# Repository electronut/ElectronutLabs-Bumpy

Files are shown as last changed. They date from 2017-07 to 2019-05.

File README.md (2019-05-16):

> **Note**: This repository has been moved to our GitLab page on May 2019, and will not receive any updates or be monitored. Please follow this link to go to the new repository: https://gitlab.com/electronutlabs-public/ElectronutLabs-Bumpy

## What is Bumpy?

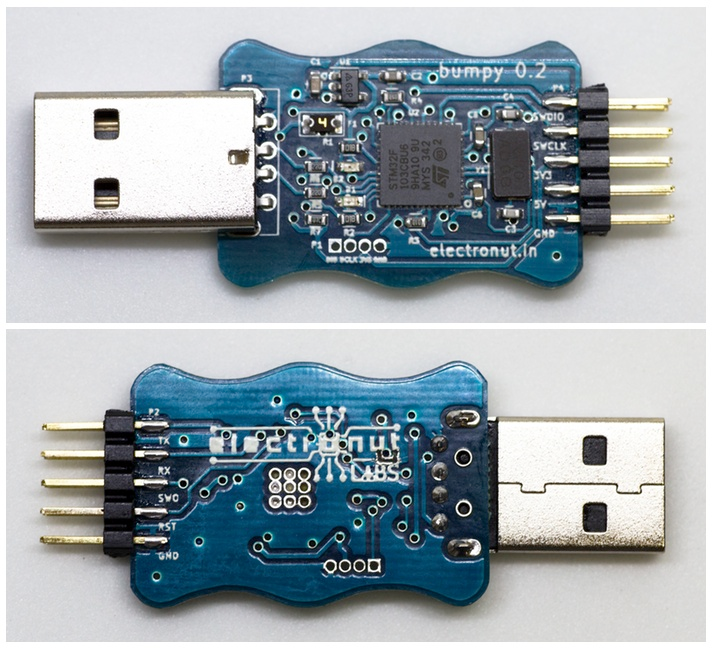
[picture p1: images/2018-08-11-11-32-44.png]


**Bumpy** is an inexpensive Open Source **blackmagic probe** compatible SWD debugger designed to
be used with ARM GDB. It supports [many platforms][3], but was primarily designed
for use with our Nordic Semiconductor nRF BLE boards.

When we built our [Bluey][1] nRF52 BLE dev board, we were looking for an inexpensive
option for our users to upload code to bluey and debug it using ARM GDB. We then came
across the [blackmagic probe][2] (BMP) project - an Open Source debugging tool for
embedded microprocessors. It greatly simplifies the debugging and code
uploading process using just ARM GDB - no need to run a GDB server or use an
additional complex tool like **openocd**. Although the BMP hardware is excellent,
it's bit beyond the budget of our target audience as an add-on programmer.
So we decided to make use of their liberal open source license and build something
that fits our budget, albeit with less capabilities.

**Bumpy** takes advantage of the **ST-Link** support of the BMP, and its design
is based on both BMP and Chinese **St-Link V2** clones available for cheap in the market.

Schematic : [download](schematic.pdf)

## Plugging in Bumpy

When you plug in Bumpy, you'll see two ports - one for blackmagic probe functionality
and the other for a UART you can use for printing debug messages without plugging
in a separate USB to serial adapter.

This is how it looks on *OS X*. (Linux should be similar.):

```
$ ls /dev/tty.usb**
/dev/tty.usbmodemD5C57BD1	/dev/tty.usbmodemD5C57BD3
```

This is how it looks on the Windows Device Manager:

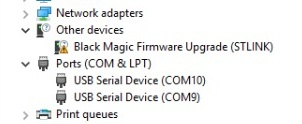
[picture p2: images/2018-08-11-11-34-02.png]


## Bumpy Firmware

Bumpy already comes with the blackmagic probe firmware. In case you need to build it, here's what you do:

### Building firmware

These instructions are for linux. First, clone bumpy firmware `git clone git@github.com:electronut/blackmagic.git -b bumpy`. Then `cd blackmagic` and run:

    make PROBE_HOST=bumpy

The directory `src` will contain the binaries.

To upload a specific version of firmware:
	
	dfu-util -s 0x08002000:leave:force -D blackmagic.bin

### Releases

We recommend using version v1.3 firmware, it has support for Nrf52840 and newer chip IDs for Nrf52832 etc., but automatic reset upon disconnect from GDB doesn't work in this one (though you can do `run` inside GDB to run the code). V1.2 is here for archival reasons.

#### Version 1.3

Download [link](https://github.com/electronut/ElectronutLabs-Bumpy/releases/download/v1.3/blackmagic.bin)

#### Version 1.2

Download [link](https://github.com/electronut/ElectronutLabs-Bumpy/releases/download/v1.2/blackmagic.bin)

#### Version 1.1

Download [link](https://github.com/electronut/ElectronutLabs-Bumpy/releases/download/v1.1/bumpy-rev1.1.bin)

## Updating Bumpy Firmware

The latest binaries are included in the [firmware](firmware) directory of this repository. You can download it directly from [here](https://github.com/electronut/ElectronutLabs-Bumpy/releases/download/v1.1/bumpy-rev1.1.bin).

In order to update the blackmagic probe firmware on Bumpy, you need to have [dfu-util](http://dfu-util.sourceforge.net/) installed in your system.

### Windows

* Download and extract the contents of **dfu-util-0.9-win64.zip** file.

* Add the location of **dfu-util.exe** executable, available in the extracted folder from above, to your
path variables.

* Ensure that dfu-util is part of your PATH variables by simply running a command prompt and typing **dfu-util**.

* Plug-in Bumpy. Wait until the onboard red LED turns on.

* In Windows, you need WinUSB or libusb drivers for dfu-util to work. These drivers can be installed using [Zadig](http://zadig.akeo.ie/).

* Run: **Zadig**.

* Select: **Black Magic Firmware Upgrade (STLINK) (Interface 4)** from the drop down menu.

* If no device is available for selection, go to: Options > List All Devices.

* Select **WinUSB** driver and click on **Install**.

* The above steps have enabled firmware update functionality over USB.

* Now, check that you are in the same directory as the **bumpy-rev1.1.bin**

* Run: `dfu-util -d 1d50:6018,:6017 -s 0x08002000:leave -D bumpy-rev1.1.bin`.

* Wait for firmware to load. The expected output is shown below:

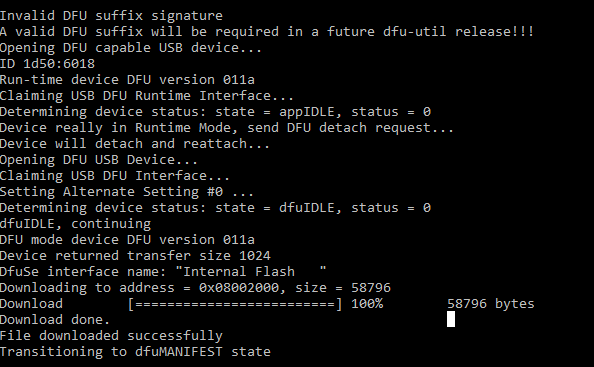
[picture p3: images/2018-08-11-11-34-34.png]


* Remove Bumpy and plugin again, to reset the chip.

The firmware has been updated successfully.

### Linux

Most Linux installations have packages for dfu-util, by default. Following are the install commands for some of these popular distributions.

**Ubuntu** & **Debian** 

`sudo apt-get install dfu-util`

**Fedora**

`sudo yum install dfu-util`

**Arch**

`sudo pacman -Sy dfu-util`

Once the installation is successful, simply plugin Bumpy and issue following command to update the firmware.

`sudo dfu-util -d 1d50:6018,:6017 -s 0x08002000:leave -D bumpy-rev1.1.bin`

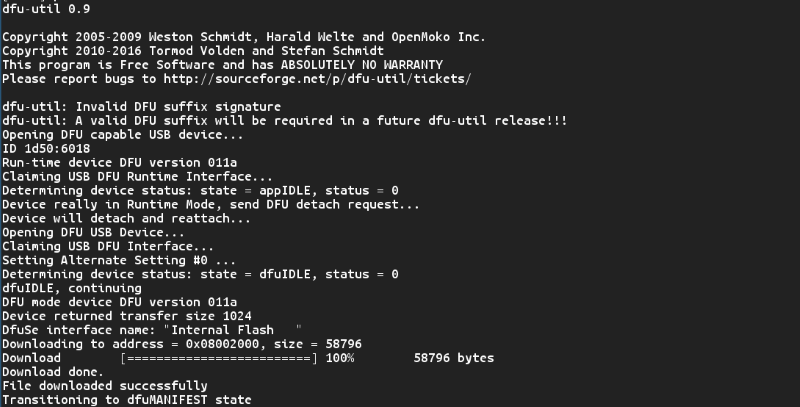
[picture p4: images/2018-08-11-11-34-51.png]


## Using Bumpy

Here are a few example of using Bumpy.

Jump To:

- [Using Bumpy with Bluey (Nordic nRF52832)](#bluey)
- [Using Bumpy with an STM32F100RB](#stm32f100)

<hr />

##  Using Bumpy with Bluey (Nordic nRF52832)

Here, we assume that you have files *blinky.hex* and *blinky.out* in the working
directory where you start GDB. (You can generate these files yourself using the
  *peripheral/blinky/pca10040/blank* example in the Nordic SDK.)

Connect the debugger to bluey as follows:

| Bumpy | bluey |
|---|---|
| 3.3 | VDD|
| GND | GND|
| SWCLK | SWCLK|
| SWDIO | SWDIO|

Here's what the hookup looks like:

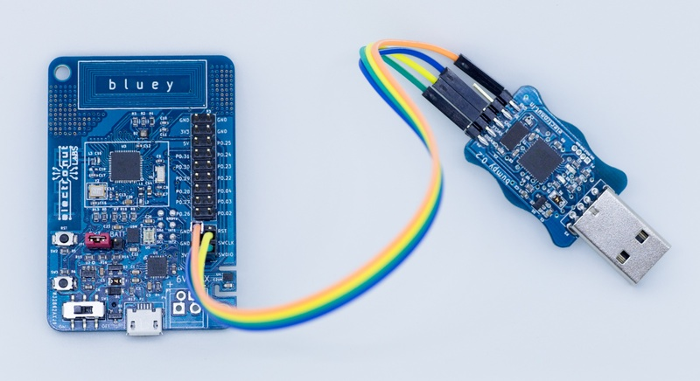
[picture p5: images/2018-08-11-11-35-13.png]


Now, open a command shell and run **arm-none-eabi-gdb**:

```
C:\Users\mahesh>arm-none-eabi-gdb
GNU gdb (GNU Tools for ARM Embedded Processors 6-2017-q1-update) 7.12.1.20170215-git
Copyright (C) 2017 Free Software Foundation, Inc.
License GPLv3+: GNU GPL version 3 or later <http://gnu.org/licenses/gpl.html>
This is free software: you are free to change and redistribute it.
There is NO WARRANTY, to the extent permitted by law.  Type "show copying"
and "show warranty" for details.
This GDB was configured as "--host=i686-w64-mingw32 --target=arm-none-eabi".
Type "show configuration" for configuration details.
For bug reporting instructions, please see:
<http://www.gnu.org/software/gdb/bugs/>.
Find the GDB manual and other documentation resources online at:
<http://www.gnu.org/software/gdb/documentation/>.
For help, type "help".
Type "apropos word" to search for commands related to "word".
(gdb)
```

Now you need to connect to the target. The Black Magic Probe hardware will
create two COM ports, and you need to connect to the first one for debugging.
(You can see the ports in the *Device Manager*.)

```
(gdb) target extended-remote COM5
Remote debugging using COM5
```

**Note**

On Windows, for ports >= `COM10`, add the prefix `\\.\`.

For example:

```
(gdb) target extended-remote COM3
(gdb) target extended-remote \\.\COM10
```

Now, we scan for targets. We're using SWD here.

```
(gdb) monitor swdp_scan
Target voltage: unknown
Available Targets:
No. Att Driver
 1      Nordic nRF52
```

You can see above that it found our nRF52 target - the chip in Bluey. Now
let's connect to it.

```
(gdb) attach 1
Attaching to Remote target
warning: No executable has been specified and target does not support
determining executable automatically.  Try using the "file" command.
0x0002099e in ?? ()
(gdb)
```

Now let's upload some code to the flash memory.

```
(gdb) file blinky.hex
Reading symbols from blinky.hex...(no debugging symbols found)...done.
```

Now let's run the program.

```
(gdb) run
Starting program: C:\mahesh\nRF5_SDK_12.2.0_f012efa\examples\peripheral\blinky\pca10040\blank\armgcc\_build\blinky.hex
```
At this point you'll be able to see the LED blinking on **bluey** in various colors.

Now we're ready to do some debugging. We'll use the *.out* file this time, since that has
the necessary code symbols required for debugging.

```
(gdb) file blinky.out
A program is being debugged already.
Are you sure you want to change the file? (y or n) y
Reading symbols from blinky.out...done.
(gdb) run
The program being debugged has been started already.
Start it from the beginning? (y or n) y
Starting program: C:\mahesh\nRF5_SDK_12.2.0_f012efa\examples\peripheral\blinky\pca10040\blank\armgcc\_build\blinky.out
```

Now press Ctrl-C.

```
Program received signal SIGINT, Interrupt.
0x00001990 in nrf_delay_us (number_of_us=500000) at ../../../../../../components/drivers_nrf/delay/nrf_delay.h:128
128     __ASM volatile (
(gdb) list
123     __STATIC_INLINE void nrf_delay_us(uint32_t number_of_us)
124     {
125         const uint32_t clock16MHz = CLOCK_FREQ_16MHz;
126         if (number_of_us)
127         {
128     __ASM volatile (
129     #if ( defined(__GNUC__) && (__CORTEX_M == (0x00U) ) )
130             ".syntax unified\n"
131     #endif
132     "1:\n"
(gdb)
```

As you can see, it's showing you the code being executed. Now let's put a breakpoint in
*main.c*:

```
(gdb) break main.c:43
Breakpoint 4 at 0x1a04: file ../../../main.c, line 43.
(gdb) run
The program being debugged has been started already.
Start it from the beginning? (y or n) y
Starting program: C:\mahesh\nRF5_SDK_12.2.0_f012efa\examples\peripheral\blinky\pca10040\blank\armgcc\_build\blinky.out

Breakpoint 4, main () at ../../../main.c:43
43                  nrf_delay_ms(500);
(gdb) list
38          while (true)
39          {
40              for (int i = 0; i < LEDS_NUMBER; i++)
41              {
42                  bsp_board_led_invert(i);
43                  nrf_delay_ms(500);
44              }
45          }
46      }
47
(gdb) p i
$2 = 0
(gdb) continue
Continuing.

Breakpoint 4, main () at ../../../main.c:43
43                  nrf_delay_ms(500);
(gdb) p i
$3 = 1
(gdb)
```

As you can see above, as we loop through, we can see *i* changing. Cool huh?

If you want to learn how to use GDB I highly recommend [Art of debugging][6] by
Norman Matloff and Peter Jay Salzman.

### Loading code with Softdevice

In the above example, we used the *blinky* code which did not have a Softdevice.
Since most of our use of this chip will use BLE and hence a Nordic Softdevice, let's
take the SDK example *ble_app_hrs* and see how to load it.

First, build *ble_app_hrs* to generate the program hex file. Then use the
Nordic *mergehex* tool to combine the softdevice and program as given below.
The softdevice cam be found in *components/softdevice* folder of the SDK.

```
c:\mahesh\tmp>mergehex -m s132_nrf52_3.0.0_softdevice.hex nrf52832_xxaa.hex -o out.hex
Parsing input hex files.
Merging files.
Storing merged file.

c:\mahesh\tmp>ls -l
total 467
-rw-r--r--    1 info     Administ   130859 May  8 08:33 nrf52832_xxaa.hex
-rw-r--r--    1 info     Administ   476926 May  8 08:35 out.hex
-rw-r--r--    1 info     Administ   346118 Jul 25  2016 s132_nrf52_3.0.0_softdevice.hex
```

Now load it using our Black Magic Probe clone as shown before.

```
(gdb) load out.hex
Loading section .sec1, size 0x964 lma 0x0
Loading section .sec2, size 0xf000 lma 0x1000
Loading section .sec3, size 0xe740 lma 0x10000
Loading section .sec4, size 0x1000 lma 0x1f000
Loading section .sec5, size 0xa5a4 lma 0x20000
Start address 0x0, load size 169544
Transfer rate: 17 KB/sec, 968 bytes/write.
(gdb) run
```

And now you'll see the HRS app running happily on **bluey**!

**Note**

`monitor erase_mass` can be used to erase the flash memory. It works for nRF52
but I am not sure if that's the case for all supported targets.

## Using the UART via USB on Bumpy

Bumpy supports UART, so you can use it for debugging your board without using up
another USB

Connect the debugger to bluey as follows:

| Bumpy | bluey |
|---|---|
| 3.3 | VDD|
| GND | GND|
| SWCLK | SWCLK|
| SWDIO | SWDIO|
| Rx | P0.TX|
| Tx | P0.RX|

*P0.TX* and *Po.RX* can be any pins - just configure them for UART in your program.

You UART setup should look something like this:

```C
static void uart_init(void)
{
    uint32_t                     err_code;
    const app_uart_comm_params_t comm_params =
    {
        RX_PIN_NUMBER, // use P0.RX
        TX_PIN_NUMBER, // use P0.TX
        RTS_PIN_NUMBER,
        CTS_PIN_NUMBER,
        APP_UART_FLOW_CONTROL_DISABLED,
        false,
        UART_BAUDRATE_BAUDRATE_Baud115200
    };

    APP_UART_FIFO_INIT( &comm_params,
                       UART_RX_BUF_SIZE,
                       UART_TX_BUF_SIZE,
                       uart_event_handle,
                       APP_IRQ_PRIORITY_LOWEST,
                       err_code);
    APP_ERROR_CHECK(err_code);

    // UART enabled
    uart_enabled = true;
}
```

##  Using Bumpy with an STM32F100RB

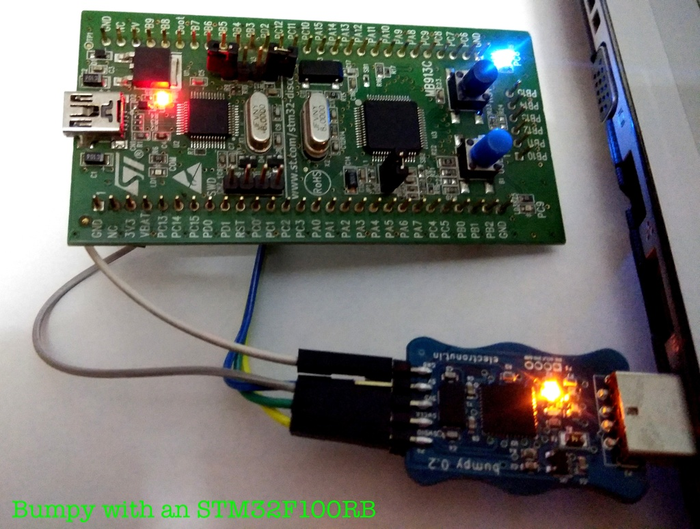
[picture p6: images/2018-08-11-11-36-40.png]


Click [here][8] to read about using Bumpy with an STM32F100RB chip. This examples compiles a minimal blink code for **STM32VLDiscovery** using **unicore-mx**.

## Using GDB in the Atom editor

[Atom][4] is gaining popularity an easy to use modern code editor. It has support for a
bewildering range of plugins, and so it has one for GDB as well - the [atom-gdb-debugger package][5].

Follow the instructions for installing the above plugin, and ensure that *arm-eabi-none-gdb* is in your PATH.

Search for "GDB Debugger" in the Atom help menu, and you'll find what you need.

The plugin is quite bare-bones and doesn't offer much more than what you get from a
command shell. But I suppose it's nice to be able to see the code and step through it from
within Atom.

## Buy a Bumpy!

Bumpy is available for purchase from our [Tindie store][7]. We also provide discounts for bulk purchases. Do email us at **info@electronut.in** if you have any questions.



[1]: http://electronut.in/portfolio/bluey/
[2]: https://github.com/blacksphere/blackmagic
[3]: https://github.com/blacksphere/blackmagic/wiki
[4]: https://atom.io/
[5]: https://atom.io/packages/atom-gdb-debugger
[6]: https://www.nostarch.com/debugging.htm
[7]: https://www.tindie.com/stores/ElectronutLabs/
[8]: https://github.com/ntavish/unicoremx-template
[9]: https://github.com/electronut/ElectronutLabs-bluey/blob/master/blackmagic-prog.md

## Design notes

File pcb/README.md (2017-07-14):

# bump
STM32F103 based Black Magic Probe clone

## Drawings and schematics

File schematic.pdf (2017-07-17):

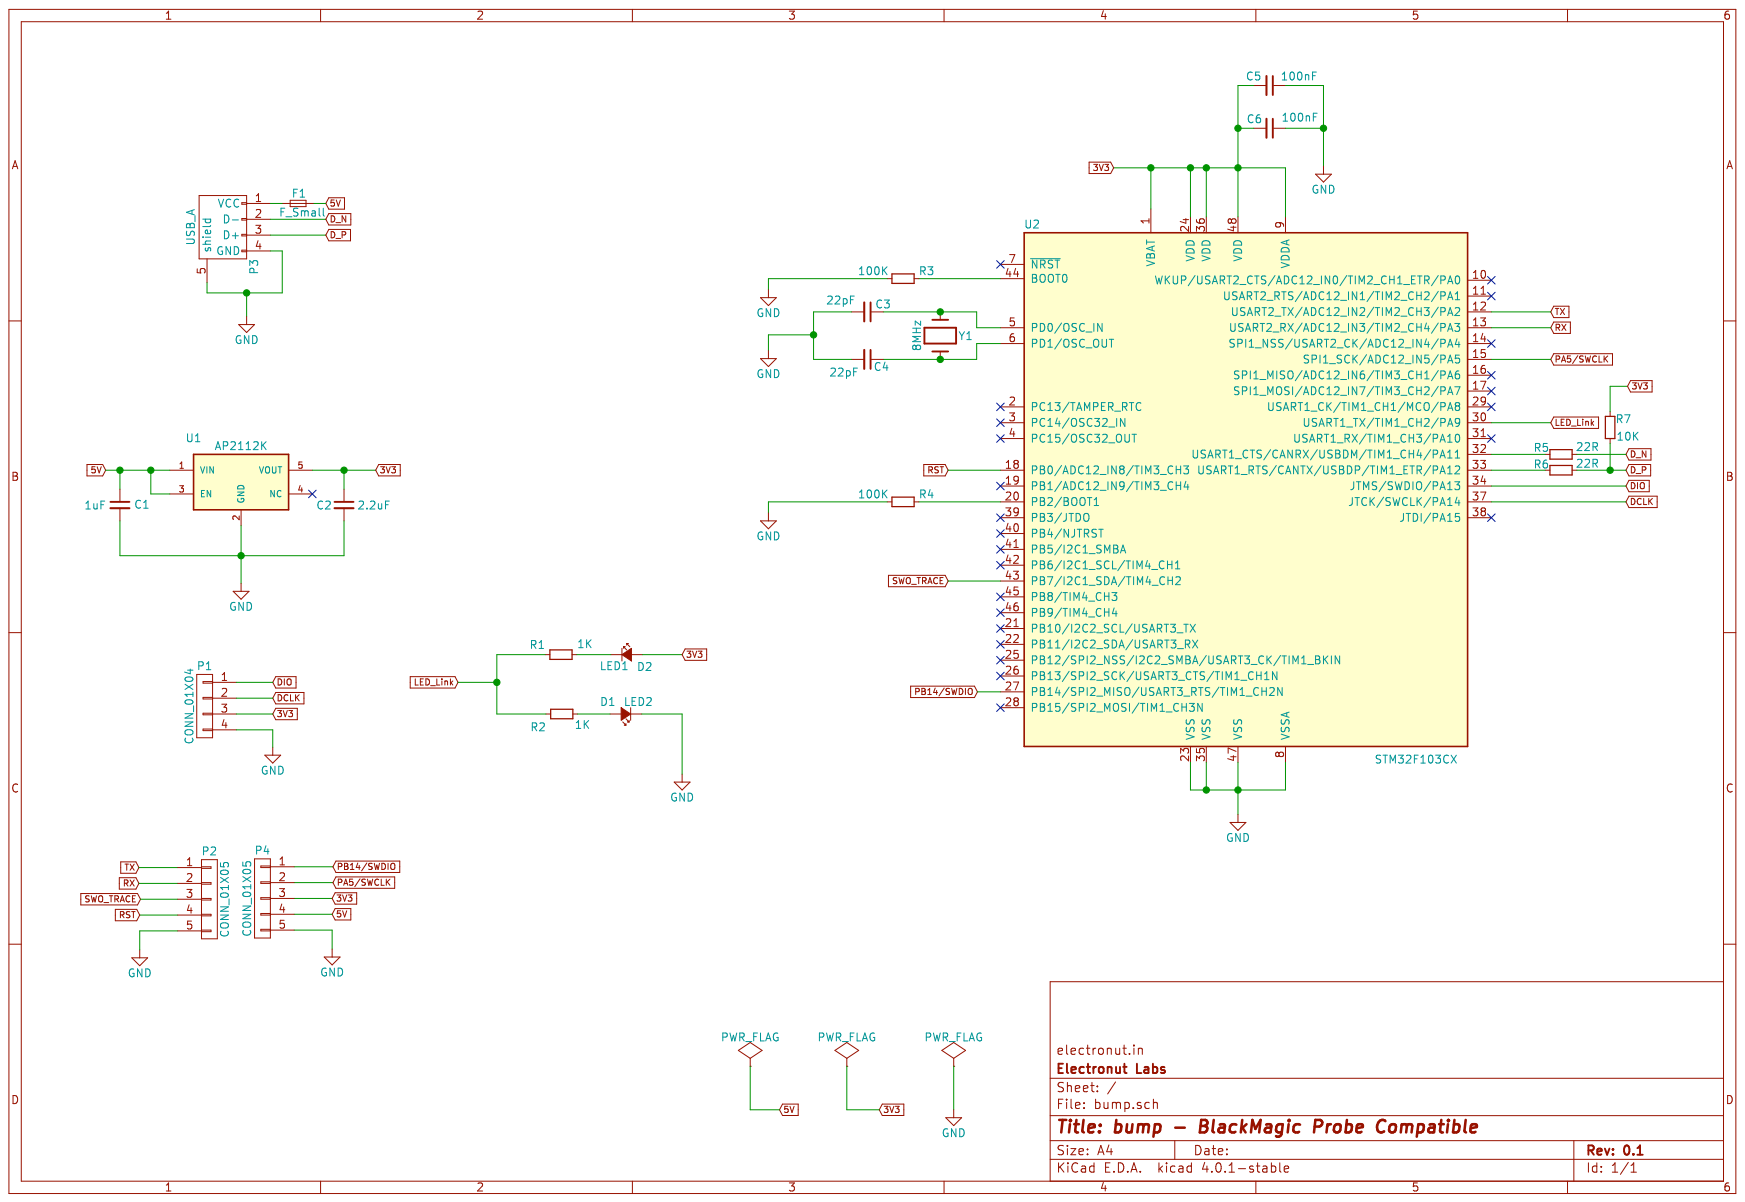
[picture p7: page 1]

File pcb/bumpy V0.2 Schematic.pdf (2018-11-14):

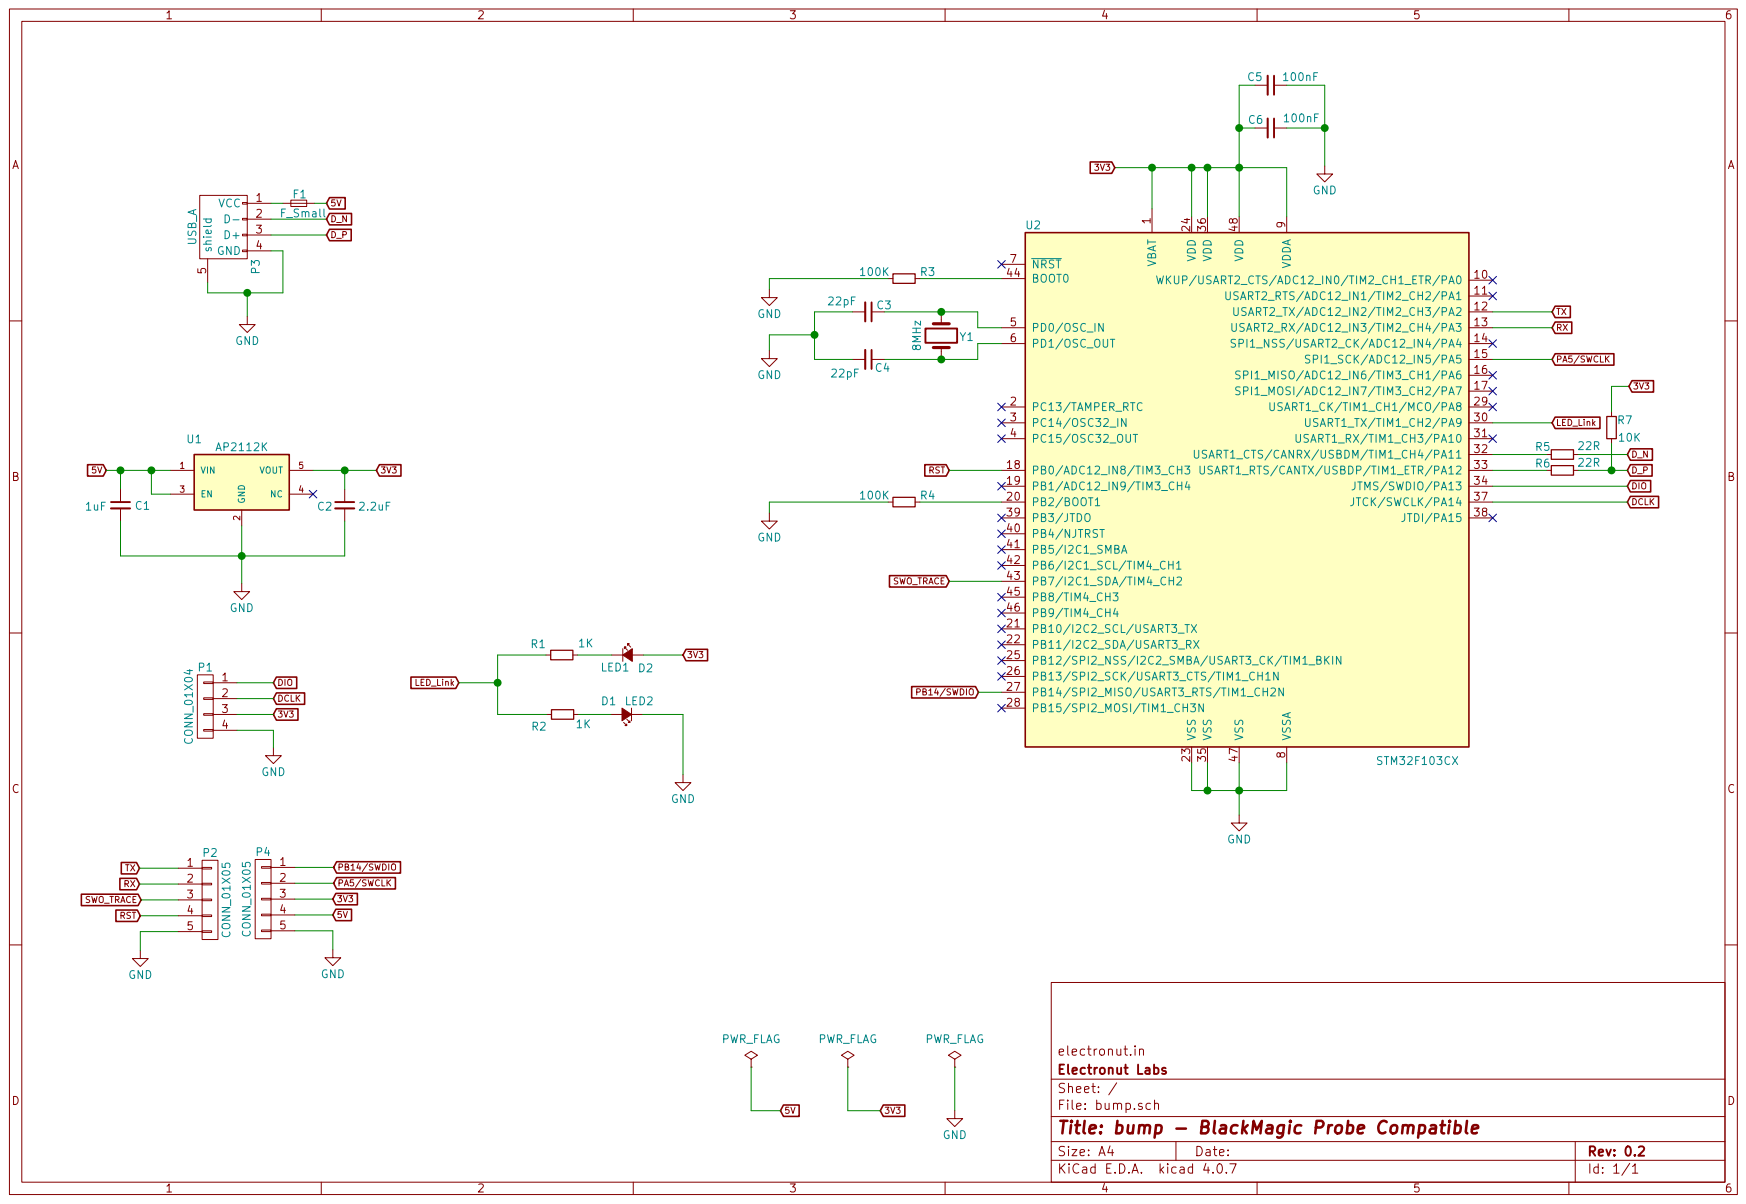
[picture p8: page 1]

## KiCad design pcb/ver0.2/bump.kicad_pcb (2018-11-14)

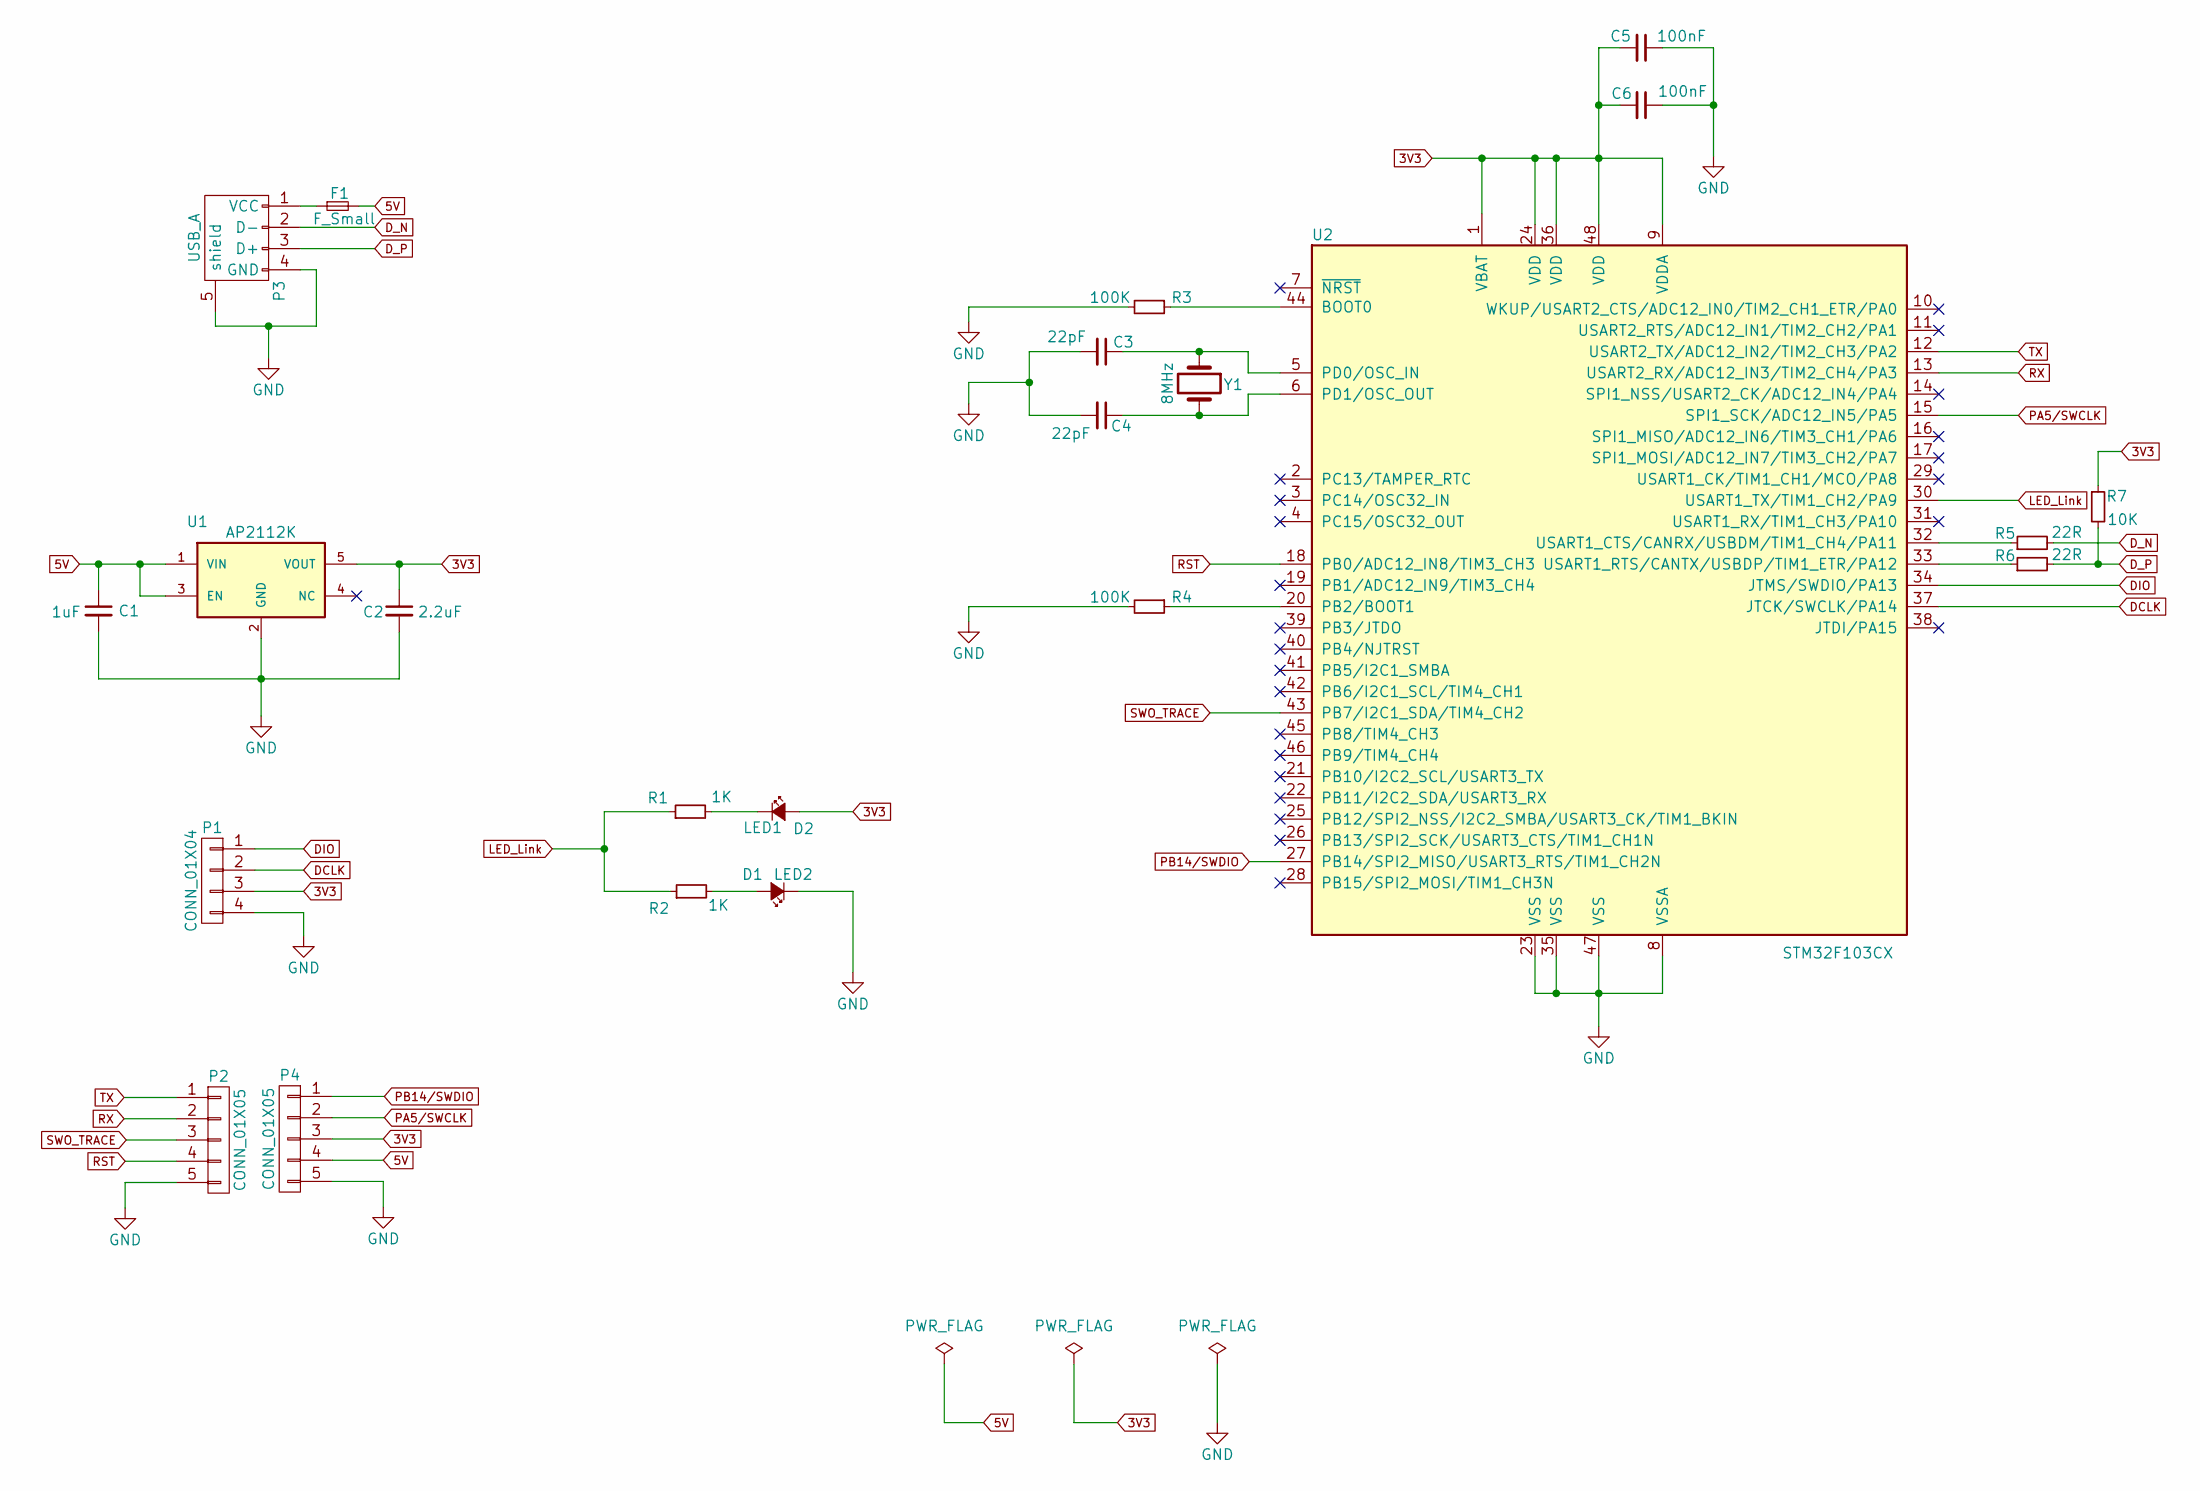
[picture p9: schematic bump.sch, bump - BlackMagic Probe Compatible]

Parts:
C1: 1uF; C_0603
C2: 2.2uF; C_0603
C3, C4: 22pF; C_0603
C5, C6: 100nF; C_0603
D1: LED2; LED_0603
D2: LED1; LED_0603
F1: F_Small; Fuse_PTC
P1: CONN_01X04; Pin_Header_Straight_1x04_1.27mm
P2, P4: CONN_01X05; Pin_Header_Straight_1x05_SMD
P3: USB_A; USBA
R1, R2: 1K; R_0603
R3, R4: 100K; R_0603
R5, R6: 22R; R_0603
R7: 10K; R_0603
U1: AP2112K; SOT-23-5
U2: STM32F103CX; QFN-48-1EP_7x7mm_Pitch0.5mm
Y1: 8MHz; ABM7

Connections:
3V3: C2.1, C5.2, C6.2, D2.2 (A), P1.3, P4.3, R7.1, U1.5 (VOUT), U2.1 (VBAT), U2.9 (VDDA), U2.24 (VDD), U2.36 (VDD), U2.48 (VDD); also elsewhere on the board
5V: C1.1, F1.2, P4.4, U1.1 (VIN), U1.3 (EN); also elsewhere on the board
DCLK: P1.2, U2.37 (JTCK/SWCLK/PA14)
DIO: P1.1, U2.34 (JTMS/SWDIO/PA13)
D_N: P3.2 (D-), R5.2
D_P: P3.3 (D+), R6.2, R7.2
GND: C1.2, C2.2, C3.2, C4.2, C5.1, C6.1, D1.1 (K), P1.4, P2.5, P3.4 (GND), P3.5 (shield), P4.5, R3.2, R4.2, U1.2 (GND), U2.8 (VSSA), U2.23 (VSS), U2.35 (VSS), U2.47 (VSS); also elsewhere on the board
LED_Link: R1.1, R2.1, U2.30 (USART1_TX/TIM1_CH2/PA9)
unnamed: C3.1, U2.5 (PD0/OSC_IN), Y1.1
unnamed: C4.1, U2.6 (PD1/OSC_OUT), Y1.2
unnamed: D1.2 (A), R2.2
unnamed: D2.1 (K), R1.2
unnamed: F1.1, P3.1 (VCC)
unnamed: R3.1, U2.44 (BOOT0)
unnamed: R4.1, U2.20 (PB2/BOOT1)
unnamed: R5.1, U2.32 (USART1_CTS/CANRX/USBDM/TIM1_CH4/PA11)
unnamed: R6.1, U2.33 (USART1_RTS/CANTX/USBDP/TIM1_ETR/PA12)
PA5/SWCLK: P4.2, U2.15 (SPI1_SCK/ADC12_IN5/PA5); also elsewhere on the board
PB14/SWDIO: P4.1, U2.27 (PB14/SPI2_MISO/USART3_RTS/TIM1_CH2N); also elsewhere on the board
RST: P2.4, U2.18 (PB0/ADC12_IN8/TIM3_CH3)
RX: P2.2, U2.13 (USART2_RX/ADC12_IN3/TIM2_CH4/PA3)
SWO_TRACE: P2.3, U2.43 (PB7/I2C1_SDA/TIM4_CH2)
TX: P2.1, U2.12 (USART2_TX/ADC12_IN2/TIM2_CH3/PA2)

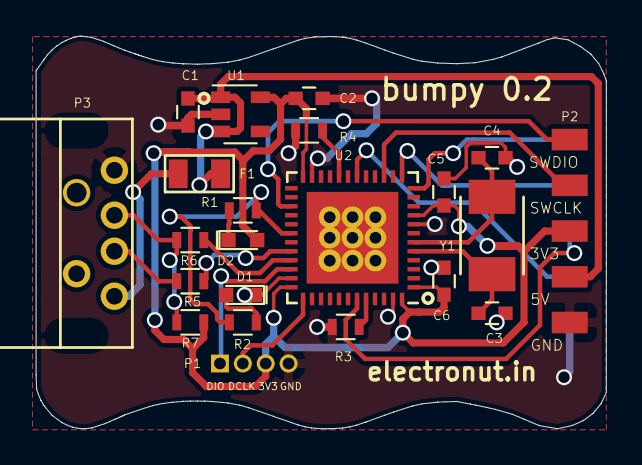
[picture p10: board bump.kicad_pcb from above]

Board: 2 copper layers, 31.7 x 21.8 mm, 23 parts (1 on the bottom side), 23 nets.

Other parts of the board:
P2#2: CONN_01X05; Pin_Header_Straight_1x05_SMD

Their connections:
3V3: P2#2.3; also elsewhere on the board
5V: P2#2.4; also elsewhere on the board
GND: P2#2.5; also elsewhere on the board
PA5/SWCLK: P2#2.2; also elsewhere on the board
PB14/SWDIO: P2#2.1; also elsewhere on the board

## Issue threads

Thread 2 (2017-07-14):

Mounting holes

JarrettR, 2017-07-14:
At least 3, preferably sized for M3 standard fit (3.3mm diameter)

electronut, 2017-07-15:
For Bumpy? It's meant to be plugged into the USB port, so I don't think mounting holes are useful...

JarrettR, 2017-07-15:
You still need them for a case!

electronut, 2017-07-15:
OK, maybe for the next version. I was thinking of a press-fit case, actually. Want to keep cost down (~USD 12)  so most people will use it without the case I think. Thanks for the feedback.

Closed 2017-07-15.

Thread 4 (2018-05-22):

No COM port for BUMPY and Cannot get target remote

kautham, 2018-05-22:
I have been trying your tutorials with your [hackable ](https://www.tindie.com/products/ElectronutLabs/hackable-nordic-nrf52832-ble-development-kit/)kit in windows. I have done all the before steps correctly without any errors. But [after the step](https://github.com/electronut/ElectronutLabs-Bumpy#-using-bumpy-with-bluey-nordic-nrf52832) where i discover my target i could not work it out. In the Device manager bumpy is not creating any new COM ports.
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

Also when i try the `monitor swdp_scan` command i get the following
```
(gdb) monitor swdp_scan
"monitor" command not supported by this target.
(gdb)
```

rishi-electronut, 2018-05-26:
@kautham

Hello Kautham,

Firstly, bumpy is working fine in your system as it is being detected in the Universal Serial Bus devices section.

In order to confirm whether COM ports are being created or not, please remove any other USB device and only plug-in bumpy. Please check if COM ports are created or not.

Secondly, which debugger are you using? If you refer to the instructions, you are supposed to install **GNU ARM Embedded Toolchain** and run

`arm-none-eabi-gdb`

to run the debugger. Is this being followed?

Also, please send me the screen-shot of the list of commands you are using.

Thanks.

kautham, 2018-06-04:
Sorry for the late response i found out the problem.It was a wrong driver installation. I used WinUSB for all the 3 ports instead of using USB Serial driver for the GBD server and UART in the Zadig application.

electronut, 2018-06-04:
OK, thanks for the update.

Closed 2018-06-04.

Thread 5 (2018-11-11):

Schematic missing from repo

mkvenkit, 2018-11-11:
Please put it at top level.

Closed 2018-11-14.

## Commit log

2017-07-17 clean up
    [bump-B.Cu.gbl, bump-B.Mask.gbs, bump-B.Paste.gbp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]
2017-08-01 updated readme with stm32
2018-08-11 move to mkdocs
    [bump.kicad_pcb, bump.sch]
2018-11-12 PCB files updated
    [bump-B.Cu.gbl, bump-B.Mask.gbs, bump-B.Paste.gbp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]
2018-11-12 Removed 0.1 directory
    [bump-B.Cu.gbl, bump-B.Mask.gbs, bump-B.Paste.gbp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]
2018-11-12 ver0.2 Schematic updated
